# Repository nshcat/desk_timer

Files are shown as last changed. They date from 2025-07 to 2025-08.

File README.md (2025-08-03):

# desk_timer

# TODOs

[ ] For some reason, I needed to add "-isystem /usr/arm-none-eabi/include/c++/14.2.0" to the `compile_commands.json` entry for `main.cxx` in order for `clangd` to find the system includes.

[ ] Compiling and linking u8g2 as a static library does not seem to work - the final `desk_timer.elf` binary is way too large (multiple megabytes big), and while having LTO enabled via the CMake LTO settings shrinks the binary again, it doesnt work on the MCU. I did have to use `-ffunction-sections` and `-fdata-sections`, maybe that messed up the final `.bin` flash image generation, because it creates individual sections for each function and data symbol?

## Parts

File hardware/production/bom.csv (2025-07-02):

Designator | Footprint | Quantity | Value | LCSC Part #
BZ1 | Buzzer_Murata_PKMCS0909E | 1 | PKMCS0909E4000-R1 | C910763
C1, C2 | 1206 | 2 | 22uF | C12891
C10, C7, C8 | 0805 | 3 | 100nF | C28233
C3, C4 | 0402 | 2 | 10pF | C32949
C5, C6 | 0402 | 2 | 12pF | C1547
C9 | 0805 | 1 | 10nF | C18741
D1 | 0402 | 1 | YELLOW GREEN | C130722
D2 | 0402 | 1 | RED | C130719
D3 | D_SOD-523 | 1 | 1N4148WT | C7420320
FB1 | 0805 | 1 | BLM21PG221SN1D | C85840
J1 | USB_C_Receptacle_G-Switch_GT-USB-7010ASV | 1 | GT-USB-7010ASV | C2988369
Q1 | SOT-323_SC-70 | 1 | 2SC4213 | C516169
R1, R2, R4, R5 | 0402 | 4 | 5K1 | C25905
R3, R6 | 0402 | 2 | 10k | C25744
R7 | 0402 | 1 | 280R | C2929998
SW1 | SW_SPST_B3U-1000P | 1 | SW_Push | C231329
U1 | LQFP-48_7x7mm_P0.5mm | 1 | STM32G0B1CBT6 | C2847904
U2 | SOT-223-3_TabPin2 | 1 | AMS1117-3.3 | C6186
Y1 | Crystal_SMD_3215-2Pin_3.2x1.5mm | 1 | 32.768 KHz, 10ppm, 12.5pf | C32346
Y2 | Crystal_SMD_3225-4Pin_3.2x2.5mm | 1 | 8 MHz, 10ppm, 10pf | C400090

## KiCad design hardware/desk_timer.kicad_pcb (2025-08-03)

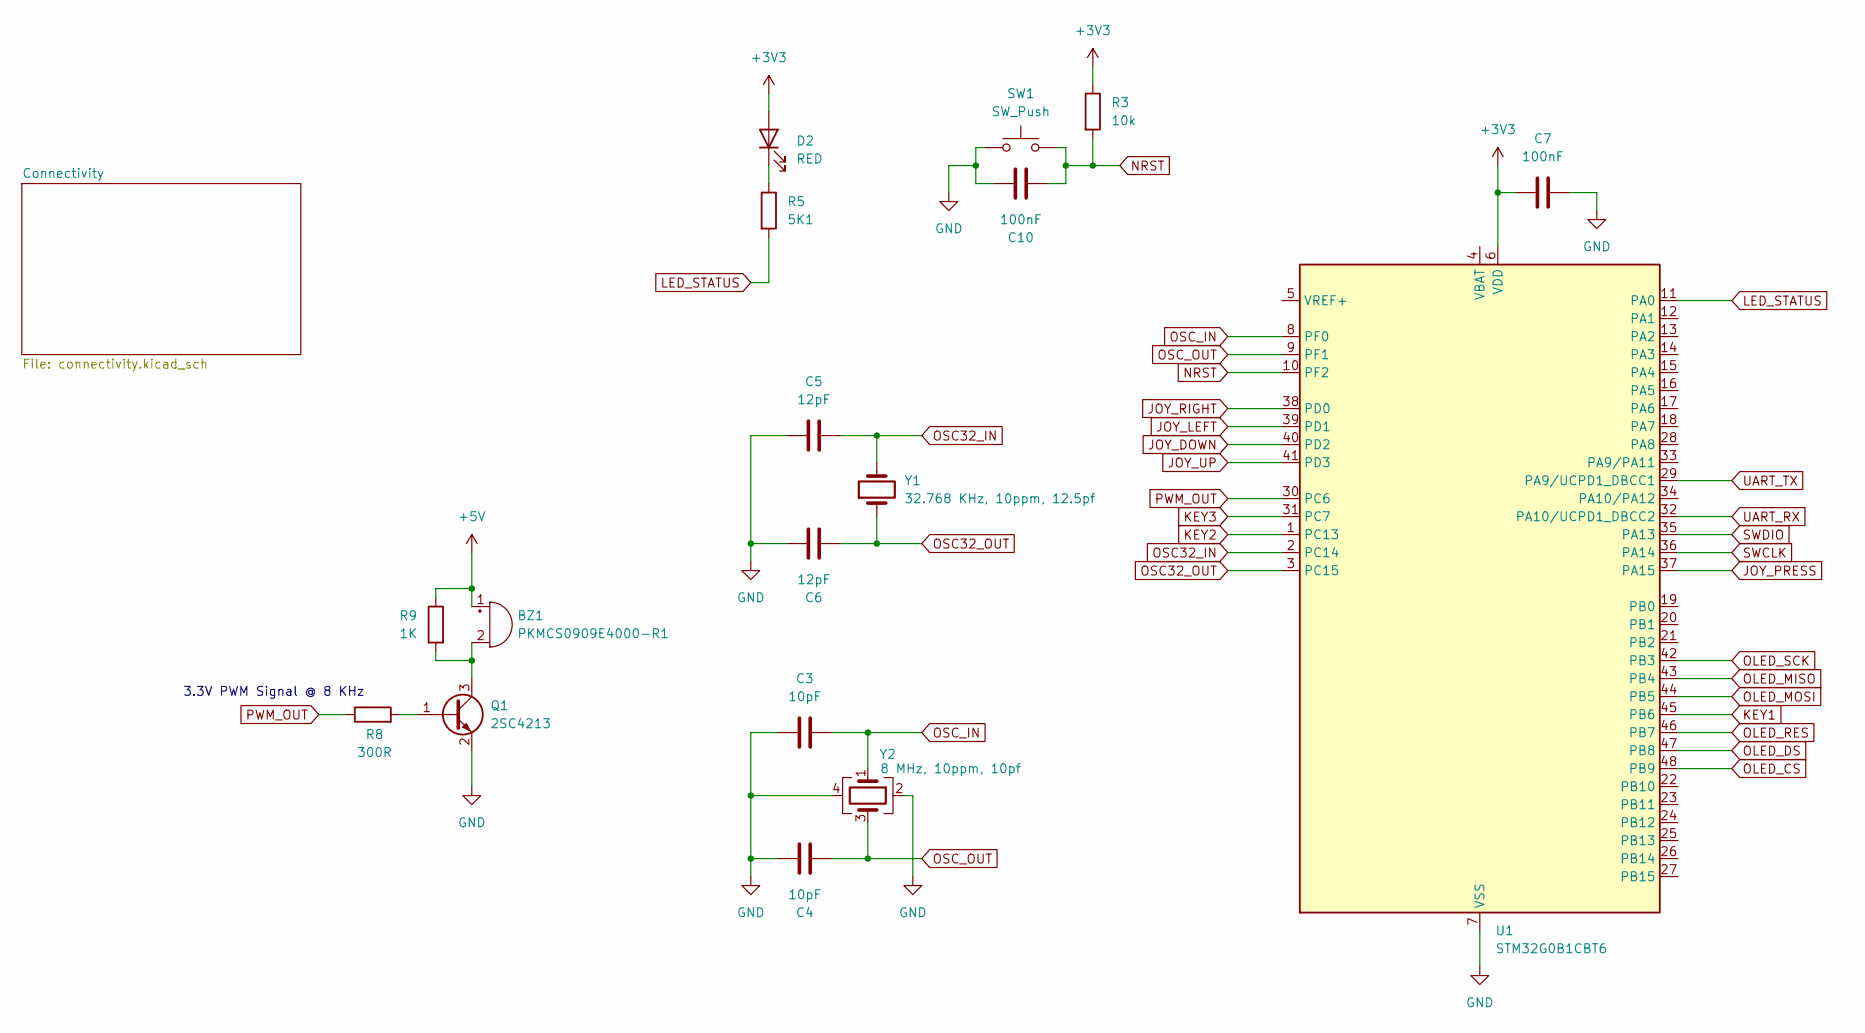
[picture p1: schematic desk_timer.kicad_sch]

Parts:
BZ1: PKMCS0909E4000-R1; Buzzer_Murata_PKMCS0909E; LCSC Part # C910763
C3, C4: 10pF; C_0402_1005Metric; LCSC Part # C32949
C5, C6: 12pF; C_0402_1005Metric; LCSC Part # C1547
C7, C10: 100nF; C_0805_2012Metric; LCSC Part # C28233
D2: RED; LED_0402_1005Metric; LCSC Part # C130719
Q1: 2SC4213; SOT-323_SC-70; LCSC Part # C516169
R3: 10k; R_0402_1005Metric; LCSC Part # C25744
R5: 5K1; R_0402_1005Metric; LCSC Part # C25905
R8: 300R; R_1206_3216Metric_Pad1.30x1.75mm_HandSolder; LCSC Part # C17887
R9: 1K; R_0402_1005Metric; LCSC Part # C11702
SW1: SW_Push; SW_SPST_B3U-1000P; LCSC Part # C231329
U1: STM32G0B1CBT6; LQFP-48_7x7mm_P0.5mm; LCSC Part # C2847904
Y1: 32.768 KHz, 10ppm, 12.5pf; Crystal_SMD_3215-2Pin_3.2x1.5mm; LCSC Part # C32346
Y2: 8 MHz, 10ppm, 10pf; Crystal_SMD_3225-4Pin_3.2x2.5mm; LCSC Part # C400090

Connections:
+3V3: C7.1, D2.2 (A), R3.1, U1.6 (VDD); also elsewhere on the board
+5V: BZ1.1 (+), R9.1; also elsewhere on the board
GND: C3.2, C4.2, C5.1, C6.2, C7.2, C10.1, Q1.2 (E), SW1.1, U1.7 (VSS), Y2.2, Y2.4; also elsewhere on the board
JOY_DOWN: U1.40 (PD2); also elsewhere on the board
JOY_LEFT: U1.39 (PD1); also elsewhere on the board
JOY_PRESS: U1.37 (PA15); also elsewhere on the board
JOY_RIGHT: U1.38 (PD0); also elsewhere on the board
JOY_UP: U1.41 (PD3); also elsewhere on the board
KEY1: U1.45 (PB6); also elsewhere on the board
KEY2: U1.1 (PC13); also elsewhere on the board
KEY3: U1.31 (PC7); also elsewhere on the board
LED_STATUS: R5.2, U1.11 (PA0)
NRST: C10.2, R3.2, SW1.2, U1.10 (PF2); also elsewhere on the board
unnamed: BZ1.2 (-), Q1.3 (C), R9.2
unnamed: D2.1 (K), R5.1
unnamed: Q1.1 (B), R8.2
OLED_CS: U1.48 (PB9); also elsewhere on the board
OLED_DS: U1.47 (PB8); also elsewhere on the board
OLED_MISO: U1.43 (PB4); also elsewhere on the board
OLED_MOSI: U1.44 (PB5); also elsewhere on the board
OLED_RES: U1.46 (PB7); also elsewhere on the board
OLED_SCK: U1.42 (PB3); also elsewhere on the board
OSC32_IN: C5.2, U1.2 (PC14), Y1.2
OSC32_OUT: C6.1, U1.3 (PC15), Y1.1
OSC_IN: C3.1, U1.8 (PF0), Y2.1
OSC_OUT: C4.1, U1.9 (PF1), Y2.3
PWM_OUT: R8.1, U1.30 (PC6)
SWCLK: U1.36 (PA14); also elsewhere on the board
SWDIO: U1.35 (PA13); also elsewhere on the board
UART_RX: U1.32 (PA10/UCPD1_DBCC2); also elsewhere on the board
UART_TX: U1.29 (PA9/UCPD1_DBCC1); also elsewhere on the board

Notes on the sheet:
3.3V PWM Signal @ 8 KHz

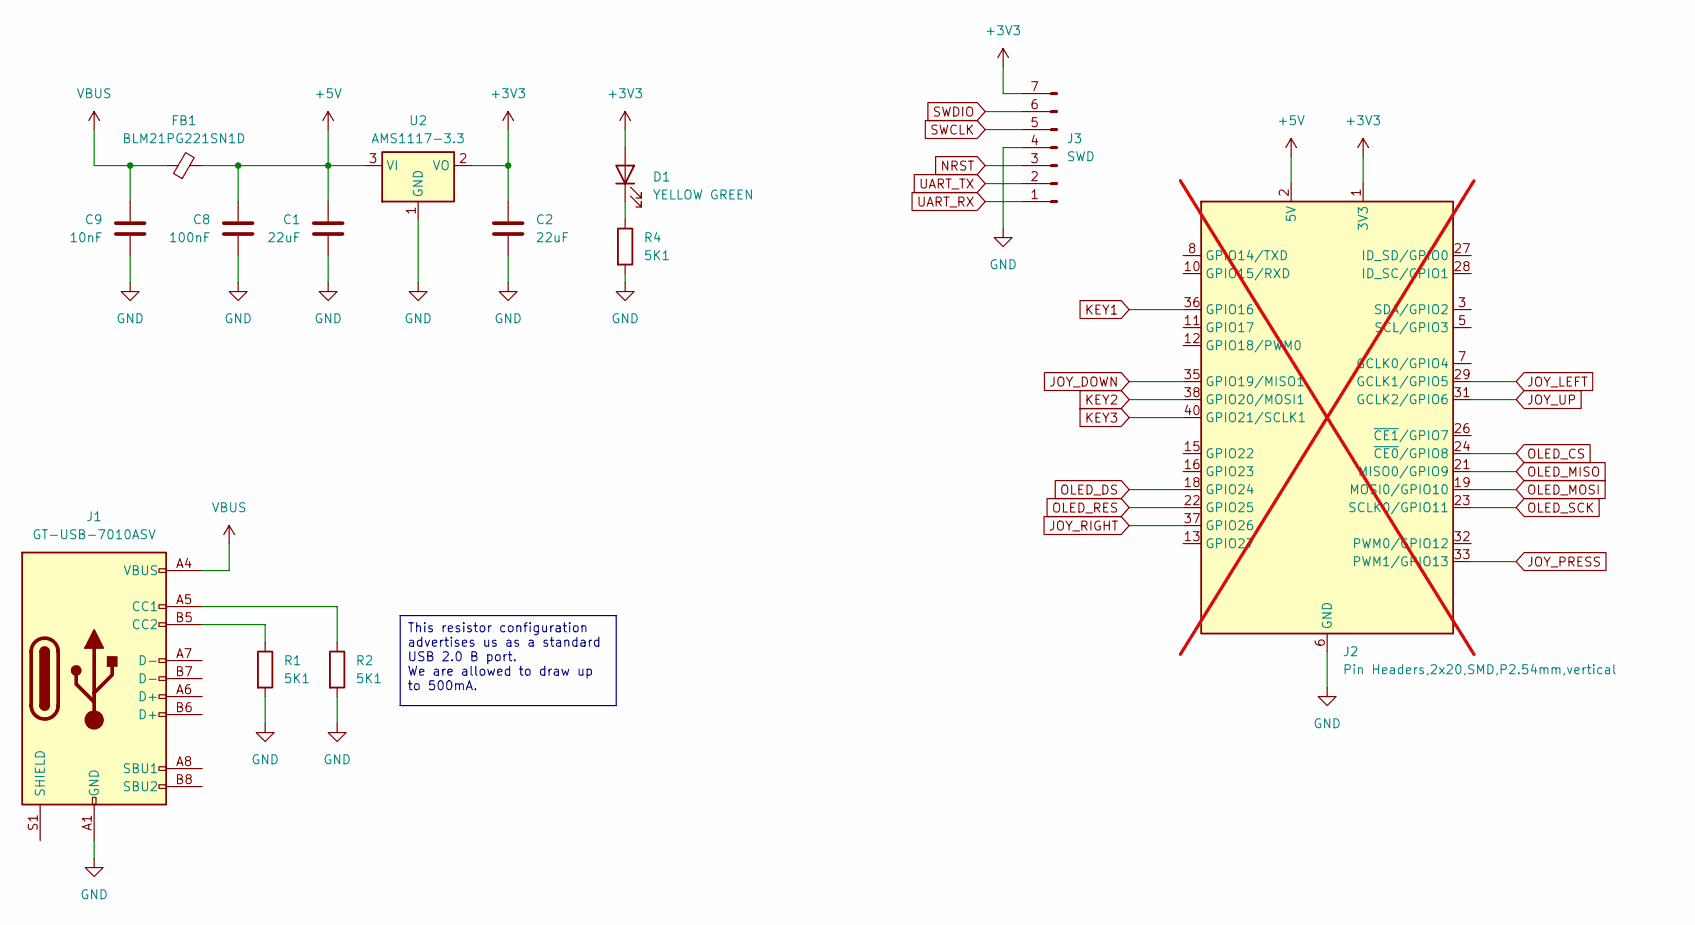
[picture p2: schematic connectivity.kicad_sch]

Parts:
C1, C2: 22uF; C_1206_3216Metric; LCSC Part # C12891
C8: 100nF; C_0805_2012Metric; LCSC Part # C28233
C9: 10nF; C_0805_2012Metric; LCSC Part # C18741
D1: YELLOW GREEN; LED_0402_1005Metric; LCSC Part # C130722
FB1: BLM21PG221SN1D; L_0805_2012Metric; LCSC Part # C85840
J1: GT-USB-7010ASV; USB_C_Receptacle_G-Switch_GT-USB-7010ASV; LCSC Part # C2988369
J2: Pin Headers,2x20,SMD,P2.54mm,vertical; PinHeader_2x20_P2.54mm_Vertical; not fitted
J3: SWD; PinHeader_1x07_P2.54mm_Horizontal
R1, R2, R4: 5K1; R_0402_1005Metric; LCSC Part # C25905
U2: AMS1117-3.3; SOT-223-3_TabPin2; LCSC Part # C6186

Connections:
+3V3: C2.1, D1.2 (A), J2.1 (3V3), J2.17 (3V3), J3.7, U2.2 (VO); also elsewhere on the board
+5V: C1.1, C8.2, FB1.2, J2.2 (5V), J2.4 (5V), U2.3 (VI); also elsewhere on the board
GND: C1.2, C2.2, C8.1, C9.1, J1.A1 (GND), J1.A12 (GND), J1.B1 (GND), J1.B12 (GND), J2.6 (GND), J2.9 (GND), J2.14 (GND), J2.20 (GND), J2.25 (GND), J2.30 (GND), J2.34 (GND), J2.39 (GND), J3.4, R1.2, R2.2, R4.2, U2.1 (GND); also elsewhere on the board
JOY_DOWN: J2.35 (GPIO19/MISO1); also elsewhere on the board
JOY_LEFT: J2.29 (GCLK1/GPIO5); also elsewhere on the board
JOY_PRESS: J2.33 (PWM1/GPIO13); also elsewhere on the board
JOY_RIGHT: J2.37 (GPIO26); also elsewhere on the board
JOY_UP: J2.31 (GCLK2/GPIO6); also elsewhere on the board
KEY1: J2.36 (GPIO16); also elsewhere on the board
KEY2: J2.38 (GPIO20/MOSI1); also elsewhere on the board
KEY3: J2.40 (GPIO21/SCLK1); also elsewhere on the board
NRST: J3.3; also elsewhere on the board
unnamed: D1.1 (K), R4.1
unnamed: J1.A5 (CC1), R2.1
unnamed: J1.B5 (CC2), R1.1
OLED_CS: J2.24 (~CE0/GPIO8); also elsewhere on the board
OLED_DS: J2.18 (GPIO24); also elsewhere on the board
OLED_MISO: J2.21 (MISO0/GPIO9); also elsewhere on the board
OLED_MOSI: J2.19 (MOSI0/GPIO10); also elsewhere on the board
OLED_RES: J2.22 (GPIO25); also elsewhere on the board
OLED_SCK: J2.23 (SCLK0/GPIO11); also elsewhere on the board
SWCLK: J3.5; also elsewhere on the board
SWDIO: J3.6; also elsewhere on the board
UART_RX: J3.1; also elsewhere on the board
UART_TX: J3.2; also elsewhere on the board
VBUS: C9.2, FB1.1, J1.A4 (VBUS), J1.A9 (VBUS), J1.B4 (VBUS), J1.B9 (VBUS)

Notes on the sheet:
This resistor configuration advertises us as a standard USB 2.0 B port. We are allowed to draw up to 500mA.

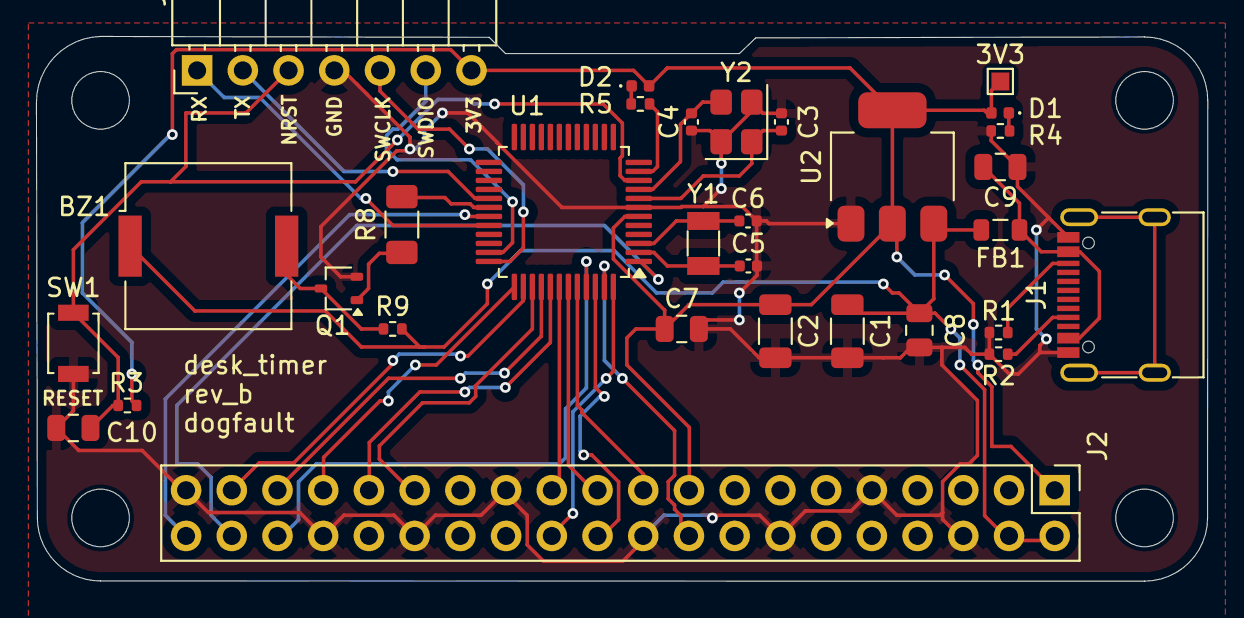
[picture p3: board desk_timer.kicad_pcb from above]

Board: 2 copper layers, 65.1 x 30.3 mm, 31 parts (0 on the bottom side), 35 nets.

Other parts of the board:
3V3: TestPoint_Pad_1.0x1.0mm

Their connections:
+3V3: 3V3.1; also elsewhere on the board

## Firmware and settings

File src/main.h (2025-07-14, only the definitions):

#define KEY_2_Pin GPIO_PIN_13
#define KEY_2_GPIO_Port GPIOC
#define KEY_2_EXTI_IRQn EXTI4_15_IRQn
#define LED_STATUS_Pin GPIO_PIN_0
#define LED_STATUS_GPIO_Port GPIOA
#define LED_STATUS2_Pin GPIO_PIN_6
#define LED_STATUS2_GPIO_Port GPIOC
#define KEY_3_Pin GPIO_PIN_7
#define KEY_3_GPIO_Port GPIOC
#define KEY_3_EXTI_IRQn EXTI4_15_IRQn
#define JOY_PRESS_Pin GPIO_PIN_15
#define JOY_PRESS_GPIO_Port GPIOA
#define JOY_PRESS_EXTI_IRQn EXTI4_15_IRQn
#define JOY_RIGHT_Pin GPIO_PIN_0
#define JOY_RIGHT_GPIO_Port GPIOD
#define JOY_RIGHT_EXTI_IRQn EXTI0_1_IRQn
#define JOY_LEFT_Pin GPIO_PIN_1
#define JOY_LEFT_GPIO_Port GPIOD
#define JOY_LEFT_EXTI_IRQn EXTI0_1_IRQn
#define JOY_DOWN_Pin GPIO_PIN_2
#define JOY_DOWN_GPIO_Port GPIOD
#define JOY_DOWN_EXTI_IRQn EXTI2_3_IRQn
#define JOY_UP_Pin GPIO_PIN_3
#define JOY_UP_GPIO_Port GPIOD
#define JOY_UP_EXTI_IRQn EXTI2_3_IRQn
#define OLED_SCK_Pin GPIO_PIN_3
#define OLED_SCK_GPIO_Port GPIOB
#define OLED_MISO_Pin GPIO_PIN_4
#define OLED_MISO_GPIO_Port GPIOB
#define OLED_MOSI_Pin GPIO_PIN_5
#define OLED_MOSI_GPIO_Port GPIOB
#define KEY_1_Pin GPIO_PIN_6
#define KEY_1_GPIO_Port GPIOB
#define KEY_1_EXTI_IRQn EXTI4_15_IRQn
#define OLED_RES_Pin GPIO_PIN_7
#define OLED_RES_GPIO_Port GPIOB
#define OLED_DS_Pin GPIO_PIN_8
#define OLED_DS_GPIO_Port GPIOB
#define OLED_CS_Pin GPIO_PIN_9
#define OLED_CS_GPIO_Port GPIOB

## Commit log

2025-06-19 Add stm32 cmake project files
2025-06-24 Added kicad project
    [bom.csv, connectivity.kicad_sch, designators.csv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]
2025-06-25 Switched to STM32G0B1, improved usage reporting, etc
    [bom.csv, connectivity.kicad_sch, designators.csv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]
2025-06-30 Added flash target
    [desk_timer.kicad_sch]
2025-07-02 Finished board
    [bom.csv, connectivity.kicad_sch, designators.csv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]
2025-07-14 Fixed display SPI. It was clocking too fast for the SH1106 controller
    [main.h]
2025-08-03 Reorganized repo
    [connectivity.kicad_sch, desk_timer.kicad_pcb, desk_timer.kicad_sch]

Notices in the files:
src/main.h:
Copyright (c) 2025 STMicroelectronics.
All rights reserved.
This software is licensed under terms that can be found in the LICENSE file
